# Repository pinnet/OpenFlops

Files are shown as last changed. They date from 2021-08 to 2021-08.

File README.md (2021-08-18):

# OpenFlops
OpenFlops is an Open Hardware Floppy Disk Drive emulator/simulator.

Board

### Summary
From [Wikipedia](https://en.wikipedia.org/wiki/Floppy_disk_hardware_emulator):
> Older models of computers, electronic keyboards and industrial automation often used floppy disk drives for data transfer. Older equipment may be difficult to replace or upgrade because of cost, requirement for continuous availability or unavailable upgrades. Proper operation may require operating system, software and data to be read and written from and to floppies, forcing users to maintain floppy drives on supporting systems.

> Floppy disks and floppy drives are gradually going out of production, and replacement of malfunctioning drives, and the systems hosting them, is becoming increasingly difficult. Floppy disks themselves are fragile, or may need to be replaced often. An alternative is to use a floppy disk hardware emulator, a device which appears to be a standard floppy drive to the old equipment by interfacing directly to the floppy disk controller, while storing data in another medium such as a USB thumb drive, Secure Digital card, or a shared drive on a computer network. Emulators can also be used as a higher-performance replacement for mechanical floppy disk drives. 

OpenFlops is an Open Hardware implementation of such an emulator, inspired from the ubiquitous Gotek hardware. It is designed to run the [FlashFloppy](https://github.com/keirf/FlashFloppy) firmware, which gives it several improvements over the original Gotek:
- Can be installed on [many different platforms](https://github.com/keirf/FlashFloppy/wiki/Host-Platforms)
- Directly supports a [wide range of image formats](https://github.com/keirf/FlashFloppy/wiki/Image-Formats)
- [Flexible track layout](https://github.com/keirf/FlashFloppy/wiki/Track-Layouts) for Raw Sector Images
- [Extremely configurable](https://github.com/keirf/FlashFloppy/wiki/FF.CFG-Configuration-File)
- Supports [AutoSwap](https://github.com/keirf/FF_AutoSwap) for games with a large number of disks
- Easily accessible pin headers for connection of a [i2c display](https://github.com/keirf/FlashFloppy/wiki/Hardware-Mods#lcd-display) (either OLED or LCD), [rotary encoder](https://github.com/keirf/FlashFloppy/wiki/Hardware-Mods#rotary-encoder) (including power)
- Built-in amplified speaker, or easily-accessible pin header for an external one
- USB connector can either be soldered on the board or connected to a pin header
- Connected Motor signal
- Emulates two drives at the same time (Not yet supported by the firmware, but [it will come](https://github.com/keirf/FlashFloppy/wiki/Donations))
- Has additional 3.3V, 5V and GND power pins
- And hey, it's Open Hardware!

All of this comes in the same form factor (and mounting holes) as the board installed in the original Gotek, hence it can be easily installed in any shell or enclosure designed for it.

### Assembly and Installation
Solder all components to the board. I suggest starting with the main microcontroller (U3), as it uses an LQFP package which is tricky to solder: the recommended technique is drag soldering, there are many videos about that on YouTube, so please look there for advice. I recommend soldering the bare minimum components needed for programming and then trying to flash it right away. This way you will be able to fix your soldering without too many components getting in the way, if needed. You will need a USB/TTL Serial converter for this: one with 3.3V I/O level is recommended, but a 5V one can be used, too (most pins on STM32 microcontrollers are 5V-tolerant, so don't worry, it's not a bad hack!). You shouldn't pay more than 1-2€ for it in any case, anyway. So, when you are ready:

- Solder U3, Y1, C3 and C5, then the programming header (the top one with power, BOOT0, TX, RX, etc.)
- Check for shorts on the 3.3V power lines, you can easily do this on the pads for C6-C10
- If your USB/Serial adapter has a 3.3V output, connect it to 3.3V on the power header, then connect ground, RX and TX
- If no 3.3V output is available, solder U4 and power the board through the 5V pin on the power header

Now you should be able to [program the STM32 microcontroller](https://github.com/keirf/FlashFloppy/wiki/Firmware-Programming). If you have difficultes you can try adding R10 (and C4) and maybe a few of C6-C10, but most likely the problem will be with the solder joints on U3, as soldering this kind of package manually is never easy, so please get a lens (or even better, a microscope) and double-check your job.

The serial adapter is only necessary for the first flashing. Subsequent updates [can be done easily via USB](https://github.com/keirf/FlashFloppy/wiki/Firmware-Update).

Note that most components are necessary, but there are a few you can skip if you are feeling lazy:
- If you are not interested in the head movement sound, you can skip the following components: SPK1, D2, R5, R6, Q7.
- If your LCD/OLED display already has pull-up resistors for the SDA/SCK lines (most do), you can skip R3 and R4.

### Configuration
Please refer to the FlashFloppy wiki for the [initial setup](https://github.com/keirf/FlashFloppy/wiki/Initial-Setup) and an overview of the [available configuration options](https://github.com/keirf/FlashFloppy/wiki/FF.CFG-Configuration-File).

Some options that you will want to override the default values of, in order to take advantage of all the features OpenFlops provides, are the following:
- `motor-delay`
- `rotary`
- `display-type`

### Releases
If you want to get this board produced, you are recommended to get [the latest release](https://github.com/SukkoPera/OpenFlops/releases) rather than the current git version, as the latter might be under development and is not guaranteed to be working.

Every release is accompanied by its Bill Of Materials (BOM) file and any relevant notes about it, which you are recommended to read carefully.

### License
The OpenFlops documentation, including the design itself, is copyright &copy; SukkoPera 2019-2020.

OpenFlops is Open Hardware licensed under the [CERN OHL v. 1.2](http://ohwr.org/cernohl).

You may redistribute and modify this documentation under the terms of the CERN OHL v.1.2. This documentation is distributed *as is* and WITHOUT ANY EXPRESS OR IMPLIED WARRANTIES whatsoever with respect to its functionality, operability or use, including, without limitation, any implied warranties OF MERCHANTABILITY, SATISFACTORY QUALITY, FITNESS FOR A PARTICULAR PURPOSE or infringement. We expressly disclaim any liability whatsoever for any direct, indirect, consequential, incidental or special damages, including, without limitation, lost revenues, lost profits, losses resulting from business interruption or loss of data, regardless of the form of action or legal theory under which the liability may be asserted, even if advised of the possibility or likelihood of such damages.

A copy of the full license is included in file [LICENSE.pdf](LICENSE.pdf), please refer to it for applicable conditions. In order to properly deal with its terms, please see file [LICENSE_HOWTO.pdf](LICENSE_HOWTO.pdf).

The contact points for information about manufactured Products (see section 4.2) are listed in file [PRODUCT.md](PRODUCT.md).

Any modifications made by Licensees (see section 3.4.b) shall be recorded in file [CHANGES.md](CHANGES.md).

The Documentation Location of the original project is https://github.com/SukkoPera/OpenFlops/.

### Support the Project
Since the project is open you are free to get the PCBs made by your preferred manufacturer, however in case you want to support the development, you can order them from PCBWay through this link:

PCB from PCBWay (https://www.pcbway.com/project/shareproject/OpenFlops_V1.html)

You get my gratitude and cheap, professionally-made and good quality PCBs, I get some credit that will help with this and [other projects](https://www.pcbway.com/project/member/shareproject/?bmbid=41100). You won't even have to worry about the various PCB options, it's all pre-configured for you!

Also, if you still have to register to that site, [you can use this link](https://www.pcbway.com/setinvite.aspx?inviteid=41100) to get some bonus initial credit (and yield me some more).

Again, if you want to use another manufacturer, feel free to, don't feel obligated :). But then you can buy me a coffee if you want:

<a href='https://ko-fi.com/L3L0U18L' target='_blank'>Buy Me a Coffee at ko-fi.com</a>

### Get Help
If you need help or have questions, you can join [the official Telegram group](https://t.me/joinchat/HUHdWBC9J9JnYIrvTYfZmg).

### Thanks
- H.M for publishing the [original Gotek schematics](doc/gotek_usb-fde_block-diagram.jpg)
- [keirf](https://github.com/keirf) for FlashFloppy
- Brian Allan for suggesting some improvements for the Speaker circuit
- Ray Bellis for suggesting adding pin headers for the USB port and speaker
- Mario Babeu for suggesting to line up the orientation of LD1 and LD2
- Patrick Kerkhof for sending me a lot of original Gotek housing for dimensional testing

# OpenFlopsXT
A remix smaller pcb with support of flashfloppy extensions and a 24pin flat flex connector for a breakout display board that supports SD cards and should fit an Amiga A500 in a mezzanine configuration. This is a work in progress and has not been proven
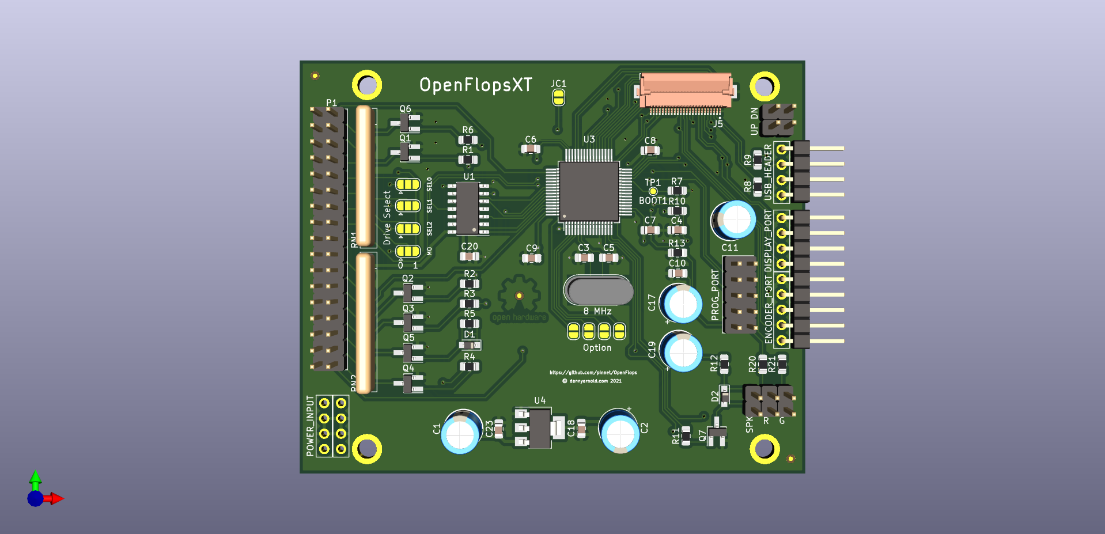
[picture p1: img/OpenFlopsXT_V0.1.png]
PCB Front


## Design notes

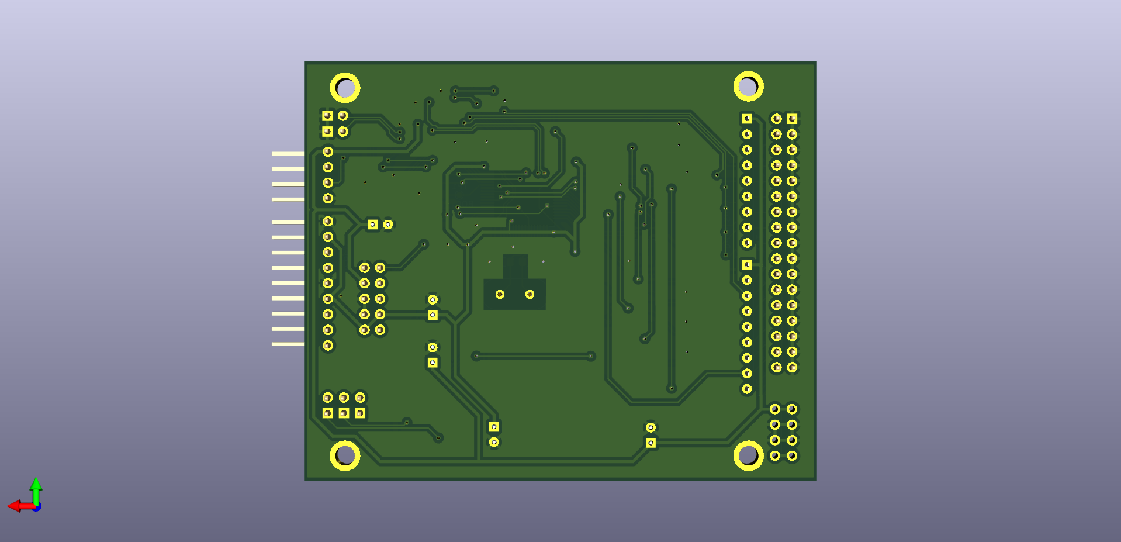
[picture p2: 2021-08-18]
img/OpenFlopsXT_V0.1.bottom.png

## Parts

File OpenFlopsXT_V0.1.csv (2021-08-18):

Source: | D:\dev\OpenFlops\OpenFlopsXT_V0.1.kicad_sch
Date: | 18/08/2021 09:18:35
Tool: | Eeschema (5.99.0-11626-g43523df843)
Generator: | C:\Program Files\KiCad\5.99\bin\scripting\plugins/bom_csv_grouped_by_value_with_fp.py
Component Count: | 77
Ref | Qnty | Value | Cmp name | Footprint | Description | Vendor
C1, | 1 | 100u | CP1 | Jumper:SolderJumper-2_P1.3mm_Open_RoundedPad1.0x1.5mm | Polarized capacitor, US symbol
C2, C11, | 2 | 100u | CP1 | Capacitor_THT:CP_Radial_D6.3mm_P2.50mm | Polarized capacitor, US symbol
C3, C5, | 2 | 22p | C | Capacitor_SMD:C_0805_2012Metric_Pad1.15x1.40mm_HandSolder | Unpolarized capacitor
C4, C6, C7, C8, C9, C10, C18, C20, C23, | 9 | 100n | C | Capacitor_SMD:C_0805_2012Metric_Pad1.15x1.40mm_HandSolder | Unpolarized capacitor
C17, C19, | 2 | 10u | CP1 | Capacitor_THT:CP_Radial_D6.3mm_P2.50mm | Polarized capacitor, US symbol
D1, D2, | 2 | 1N4148 | D | Diode_SMD:D_SOD-323_HandSoldering | Diode
FID1, FID2, FID3, | 3 | Fiducial | Fiducial | Fiducial:Fiducial_0.75mm_Mask1.5mm | Fiducial Marker
H1, H2, H3, H4, | 4 | MountingHole_Pad | MountingHole_Pad | OpenFlops:MountingHole_M3_Pad | Mounting Hole with connection
J1, | 1 | UP | Conn_01x02 | OpenFlops:PinHeader_1x02_P2.54mm_Mute | Generic connector, single row, 01x02, script generated (kicad-library-utils/schlib/autogen/connector/)
J2, | 1 | DN | Conn_01x02 | OpenFlops:PinHeader_1x02_P2.54mm_Mute | Generic connector, single row, 01x02, script generated (kicad-library-utils/schlib/autogen/connector/)
J3, | 1 | R | Conn_01x02 | OpenFlops:PinHeader_1x02_P2.54mm_Mute | Generic connector, single row, 01x02, script generated (kicad-library-utils/schlib/autogen/connector/)
J4, | 1 | G | Conn_01x02 | OpenFlops:PinHeader_1x02_P2.54mm_Mute | Generic connector, single row, 01x02, script generated (kicad-library-utils/schlib/autogen/connector/)
J5, | 1 | Conn_01x22_Female | Conn_01x22_Female | CM4IO:Hirose_FH12-22S-0.5SH_1x22-1MP_P0.50mm_Horizontal | Generic connector, single row, 01x22, script generated (kicad-library-utils/schlib/autogen/connector/)
J6, | 1 | OSHW_LOGO | Conn_01x01 | Symbol:OSHW-Logo2_9.8x8mm_Copper | Generic connector, single row, 01x01, script generated (kicad-library-utils/schlib/autogen/connector/)
JC1, | 1 | Jumper | SolderJumper_2_Open | Jumper:SolderJumper-2_P1.3mm_Open_RoundedPad1.0x1.5mm | Solder Jumper, 2-pole, open
JP1, | 1 | SEL0 | SolderJumper_3_Open | Jumper:SolderJumper-3_P1.3mm_Open_RoundedPad1.0x1.5mm | Solder Jumper, 3-pole, open
JP2, | 1 | SEL1 | SolderJumper_3_Open | Jumper:SolderJumper-3_P1.3mm_Open_RoundedPad1.0x1.5mm | Solder Jumper, 3-pole, open
JP3, | 1 | SEL2 | SolderJumper_3_Open | Jumper:SolderJumper-3_P1.3mm_Open_RoundedPad1.0x1.5mm | Solder Jumper, 3-pole, open
JP4, | 1 | MO | SolderJumper_3_Open | Jumper:SolderJumper-3_P1.3mm_Open_RoundedPad1.0x1.5mm | Solder Jumper, 3-pole, open
JP5, JP6, JP7, JP8, | 4 | SolderJumper_2_Open | SolderJumper_2_Open | Jumper:SolderJumper-2_P1.3mm_Open_RoundedPad1.0x1.5mm | Solder Jumper, 2-pole, open
P1, | 1 | FLOPPY_CONN | Conn_02x17_Odd_Even | Connector_PinHeader_2.54mm:PinHeader_2x17_P2.54mm_Vertical | Generic connector, double row, 02x17, odd/even pin numbering scheme (row 1 odd numbers, row 2 even numbers), script generated (kicad-library-utils/schlib/autogen/connector/)
P2, | 1 | POWER_INPUT | Conn_01x04_Male | OpenFlops:PinHeader_1x04_P2.54mm_Vertical_Power | Generic connector, single row, 01x04, script generated (kicad-library-utils/schlib/autogen/connector/)
P3, | 1 | POWER_PASSTHRU | Conn_01x04_Male | OpenFlops:PinHeader_1x04_P2.54mm_Vertical_Power | Generic connector, single row, 01x04, script generated (kicad-library-utils/schlib/autogen/connector/)
P4, | 1 | PROG_PORT | Conn_02x05_Odd_Even | OpenFlops:PinHeader_2x05_P2.54mm_Vertical | Generic connector, double row, 02x05, odd/even pin numbering scheme (row 1 odd numbers, row 2 even numbers), script generated (kicad-library-utils/schlib/autogen/connector/)
P6, | 1 | ENCODER_PORT | Conn_01x05 | OpenFlops:PinHeader_1x05_P2.54mm_Vertical | Generic connector, single row, 01x05, script generated (kicad-library-utils/schlib/autogen/connector/)
P7, | 1 | DISPLAY_PORT | Conn_01x04 | OpenFlops:PinHeader_1x04_P2.54mm_Vertical | Generic connector, single row, 01x04, script generated (kicad-library-utils/schlib/autogen/connector/)
P8, | 1 | USB_HEADER | Conn_01x04 | OpenFlops:PinHeader_1x04_P2.54mm_Vertical | Generic connector, single row, 01x04, script generated (kicad-library-utils/schlib/autogen/connector/)
P9, | 1 | SPK | Conn_01x02 | OpenFlops:PinHeader_1x02_P2.54mm_Mute | Generic connector, single row, 01x02, script generated (kicad-library-utils/schlib/autogen/connector/)
Q1, Q2, Q3, Q4, Q5, Q6, | 6 | BSS138 | MOS_N_GSD-w_transistor | Package_TO_SOT_SMD:SOT-23_Handsoldering
Q7, | 1 | MMBT3904 | MMBT3904 | Package_TO_SOT_SMD:SOT-23_Handsoldering | 0.2A Ic, 40V Vce, Small Signal NPN Transistor, SOT-23
R1, R2, R3, R4, R5, R6, R11, | 7 | 1K | R | Resistor_SMD:R_0805_2012Metric_Pad1.15x1.40mm_HandSolder | Resistor
R7, R10, R13, | 3 | 4k7 | R | Resistor_SMD:R_0805_2012Metric_Pad1.15x1.40mm_HandSolder | Resistor
R8, R9, R12, | 3 | 22 | R | Resistor_SMD:R_0805_2012Metric_Pad1.15x1.40mm_HandSolder | Resistor
R20, R21, | 2 | 1k | R | Resistor_SMD:R_0805_2012Metric_Pad1.15x1.40mm_HandSolder | Resistor
RN1, RN2, | 2 | R_Network08 | R_Network08 | Resistor_THT:R_Array_SIP9 | 8 resistor network, star topology, bussed resistors, small symbol
TP1, | 1 | BOOT1 | TestPoint | TestPoint:TestPoint_Pad_D1.0mm | test point
U1, | 1 | 74HCT04 | 74HC04 | Package_SO:SOIC-14_3.9x8.7mm_P1.27mm | Hex Inverter
U3, | 1 | STM32F105RBT6 | STM32F105RBTx | OpenFlops:LQFP-64_Handsoldering | ARM Cortex-M3 MCU, 128KB flash, 64KB RAM, 72MHz, 2-3.6V, 51 GPIO, LQFP-64
U4, | 1 | LM1117-3.3 | LM1117-3.3 | Package_TO_SOT_SMD:SOT-223-3_TabPin2 | 800mA Low-Dropout Linear Regulator, 3.3V fixed output, TO-220/TO-252/TO-263/SOT-223
Y1, | 1 | 8 MHz | Crystal | Crystal:Crystal_HC49-U_Vertical | Two pin crystal

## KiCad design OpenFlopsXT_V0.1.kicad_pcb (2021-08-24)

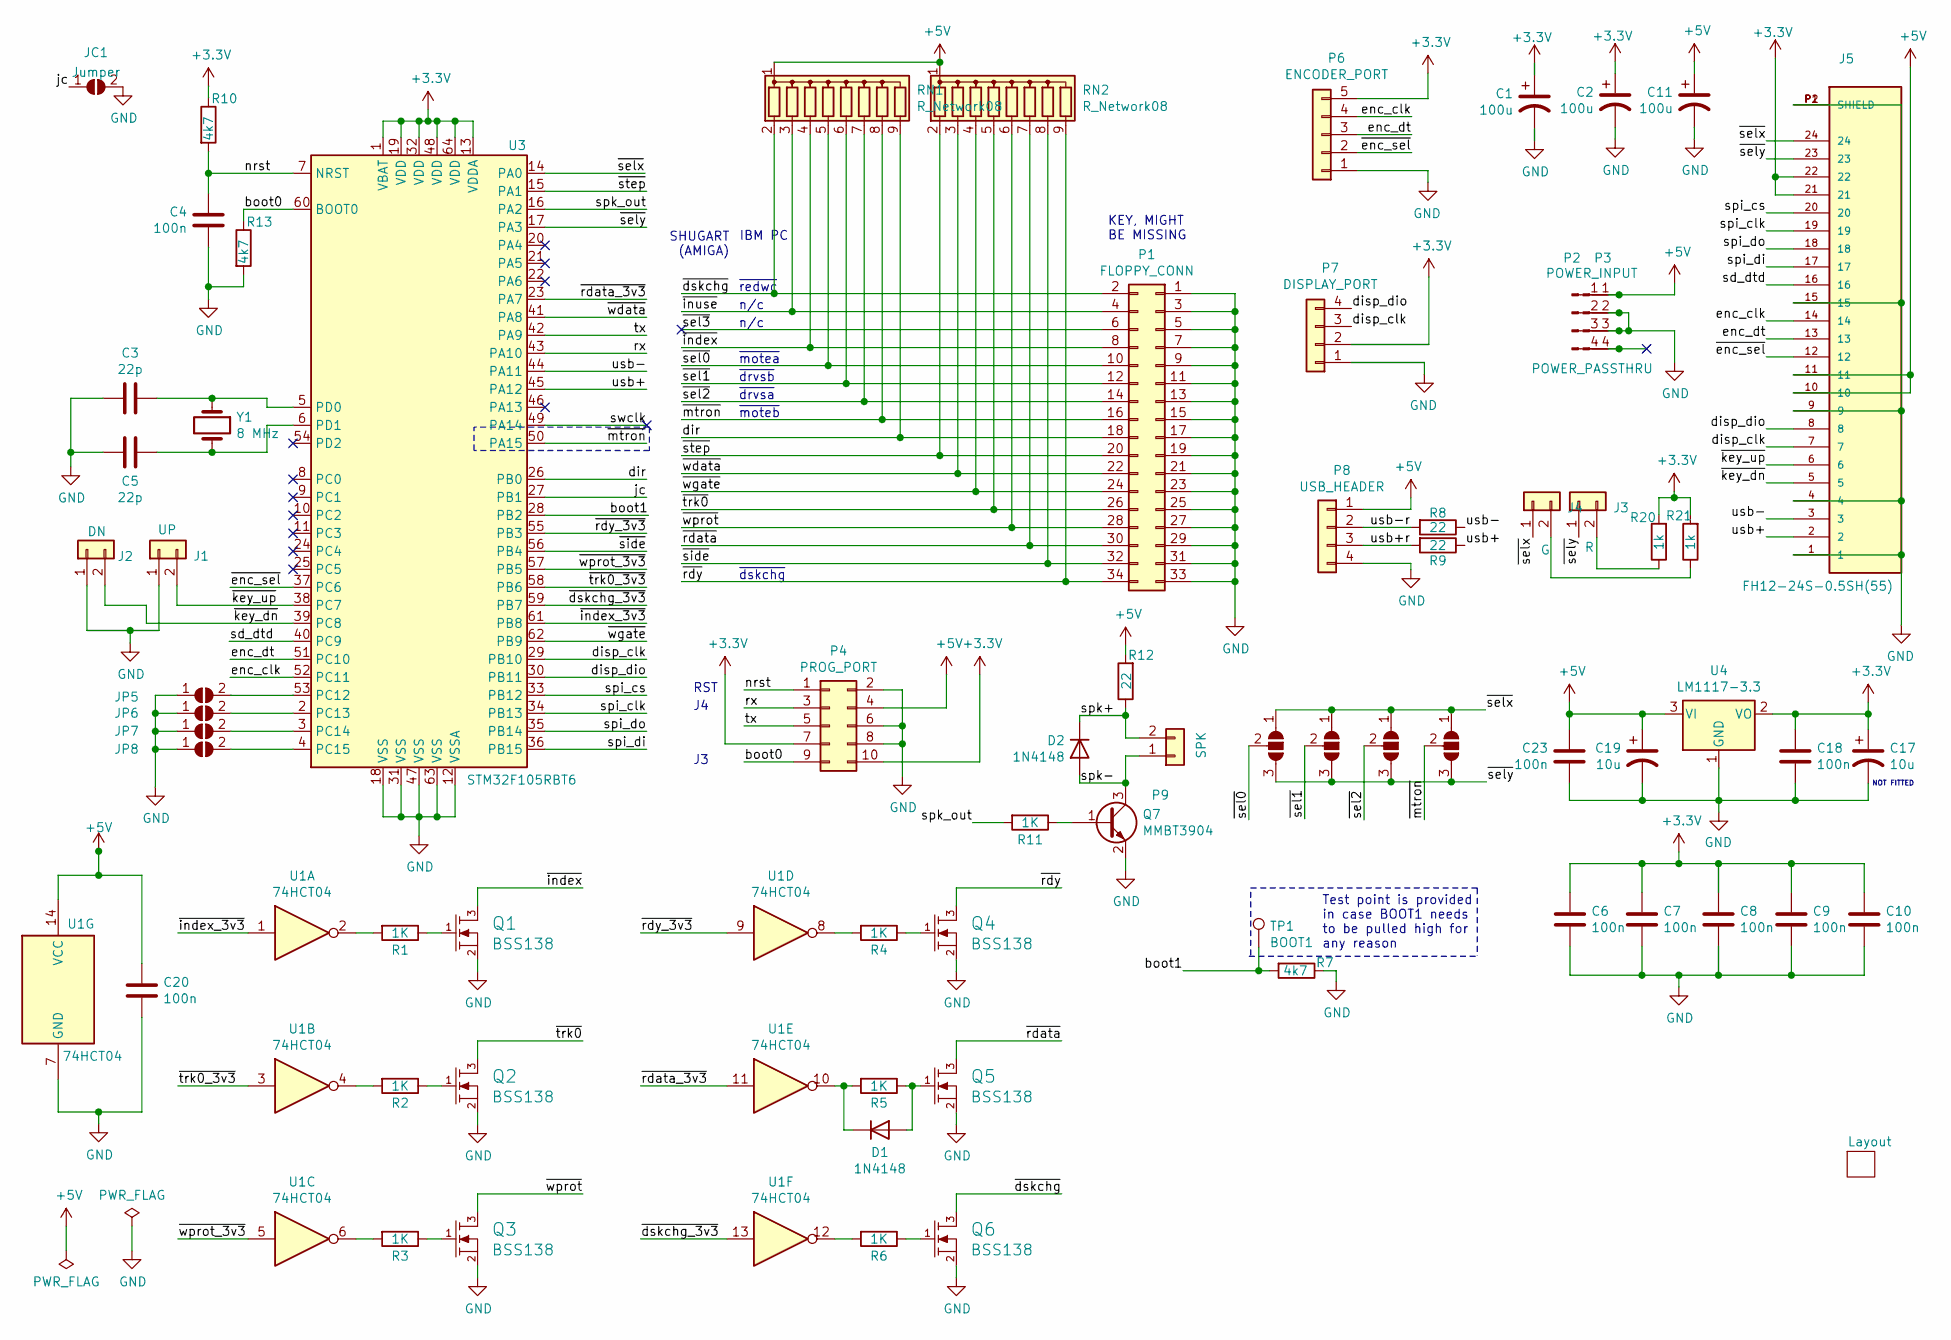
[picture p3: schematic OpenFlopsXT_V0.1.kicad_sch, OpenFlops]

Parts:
C1: 100u; SolderJumper-2_P1.3mm_Open_RoundedPad1.0x1.5mm
C2, C11: 100u; CP_Radial_D6.3mm_P2.50mm
C3, C5: 22p; C_0805_2012Metric_Pad1.15x1.40mm_HandSolder; MFG Part Num MULTILAYER CERAMIC CAPACITORS MLCC - SM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; JLCPCB PN CL21C220JBANNNC
C4, C6, C7, C8, C9, C10, C18, C20, C23: 100n; C_0805_2012Metric_Pad1.15x1.40mm_HandSolder; MFG Part Num MULTILAYER CERAMIC CAPACITORS MLCC - SM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; JLCPCB PN CC0805KRX7R9BB104
C17, C19: 10u; CP_Radial_D6.3mm_P2.50mm
D1, D2: 1N4148; D_SOD-323_HandSoldering; MFG Part Num SWITCHING DIODE 100V 150MA 1.25V @ 150M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; JLCPCB PN 1N4148WS
J1: UP; PinHeader_1x02_P2.54mm_Mute
J2: DN; PinHeader_1x02_P2.54mm_Mute
J3: R; PinHeader_1x02_P2.54mm_Mute
J4: G; PinHeader_1x02_P2.54mm_Mute
J5: FH12-24S-0.5SH(55); HRS_FH12-24S-0.5SH(55)
JC1: Jumper; SolderJumper-2_P1.3mm_Open_RoundedPad1.0x1.5mm
JP1: SEL0; SolderJumper-3_P1.3mm_Open_RoundedPad1.0x1.5mm
JP2: SEL1; SolderJumper-3_P1.3mm_Open_RoundedPad1.0x1.5mm
JP3: SEL2; SolderJumper-3_P1.3mm_Open_RoundedPad1.0x1.5mm
JP4: MO; SolderJumper-3_P1.3mm_Open_RoundedPad1.0x1.5mm
JP5, JP6, JP7, JP8: SolderJumper_2_Open; SolderJumper-2_P1.3mm_Open_RoundedPad1.0x1.5mm
P1: FLOPPY_CONN; PinHeader_2x17_P2.54mm_Vertical
P2: POWER_INPUT; PinHeader_1x04_P2.54mm_Vertical_Power
P3: POWER_PASSTHRU; PinHeader_1x04_P2.54mm_Vertical_Power
P4: PROG_PORT; PinHeader_2x05_P2.54mm_Vertical
P6: ENCODER_PORT; PinHeader_1x05_P2.54mm_Vertical
P7: DISPLAY_PORT; PinHeader_1x04_P2.54mm_Vertical
P8: USB_HEADER; PinHeader_1x04_P2.54mm_Vertical
P9: SPK; PinHeader_1x02_P2.54mm_Mute
Q1, Q2, Q3, Q4, Q5, Q6: BSS138; SOT-23_Handsoldering; MFG Part Num MOSFET N TRENCH 50V 220MA 1.5V @ 1MA 3.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; JLCPCB PN BSS138
Q7: MMBT3904; SOT-23_Handsoldering; MFG Part Num TRANSISTORS (NPN/PNP) NPN 200MA 40V SOT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; JLCPCB PN MMBT3904
R1, R2, R3, R4, R5, R6: 1K; R_0805_2012Metric_Pad1.15x1.40mm_HandSolder; MFG Part Num CHIP RESISTOR - SURFACE MOUNT 1KOHMS ±1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; JLCPCB PN 0805W8F1001T5E
R7, R10, R13: 4k7; R_0805_2012Metric_Pad1.15x1.40mm_HandSolder; MFG Part Num CHIP RESISTOR - SURFACE MOUNT 4.7KOHMS 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; JLCPCB PN 0805W8F4701T5E
R8, R9, R12: 22; R_0805_2012Metric_Pad1.15x1.40mm_HandSolder; MFG Part Num CHIP RESISTOR - SURFACE MOUNT 22OHMS ±1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; JLCPCB PN 0805W8F220JT5E
R11: 1K; R_0805_2012Metric_Pad1.15x1.40mm_HandSolder
R20, R21: 1k; R_0805_2012Metric_Pad1.15x1.40mm_HandSolder
RN1, RN2: R_Network08; R_Array_SIP9
TP1: BOOT1; TestPoint_Pad_D1.0mm
U1: 74HCT04; SOIC-14_3.9x8.7mm_P1.27mm; MFG Part Num GATES AND INVERTERS SOIC-14_150MIL ROHS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; JLCPCB PN 74HCT04D
U3: STM32F105RBT6; LQFP-64_Handsoldering; MFG Part Num ST MICROELECTRONICS LQFP-64_10X10X05P R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; JLCPCB PN STM32F105RBT6
U4: LM1117-3.3; SOT-223-3_TabPin2; MFG Part Num LOW DROPOUT REGULATORS(LDO) POSITIVE FI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; JLCPCB PN AMS1117-3.3
Y1: 8 MHz; Crystal_HC49-U_Vertical

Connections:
+3V3: C1.1, C2.1, C6.1, C7.1, C8.1, C9.1, C10.1, C17.1, C18.1, J5.21, J5.22, P4.7, P4.10, P6.5, P7.2, R10.1, R20.2, R21.2, U3.1 (VBAT), U3.13 (VDDA), U3.19 (VDD), U3.32 (VDD), U3.48 (VDD), U3.64 (VDD), U4.2 (VO)
+5V: C11.1, C19.1, C20.1, C23.1, J5.10, J5.11, P2.1, P3.1, P4.4, P8.1, R12.2, RN1.1 (common), RN2.1 (common), U1.14 (VCC), U4.3 (VI)
/boot0: P4.9, R13.1, U3.60 (BOOT0)
/boot1: R7.2, TP1.1, U3.28 (PB2)
/dir: P1.18, RN1.9 (R8), U3.26 (PB0)
/disp_clk: J5.7, P7.3, U3.29 (PB10)
/disp_dio: J5.8, P7.4, U3.30 (PB11)
/enc_clk: J5.14, P6.4, U3.52 (PC11)
/enc_dt: J5.13, P6.3, U3.51 (PC10)
/jc: JC1.1 (A), U3.27 (PB1)
/nrst: C4.1, P4.1, R10.2, U3.7 (NRST)
/rx: P4.3, U3.43 (PA10)
/sd_dtd: J5.16, U3.40 (PC9)
/spi_clk: J5.19, U3.34 (PB13)
/spi_cs: J5.20, U3.33 (PB12)
/spi_di: J5.17, U3.36 (PB15)
/spi_do: J5.18, U3.35 (PB14)
/spk+: D2.1 (K), P9.2, R12.1
/spk-: D2.2 (A), P9.1, Q7.3 (C)
/spk_out: R11.2, U3.16 (PA2)
/swclk: U3.49 (PA14)
/tx: P4.5, U3.42 (PA9)
/usb+: J5.2, R9.1, U3.45 (PA12)
/usb+r: P8.3, R9.2
/usb-: J5.3, R8.1, U3.44 (PA11)
/usb-r: P8.2, R8.2
/~dskchg_3v3: U1.13, U3.59 (PB7)
/~dskchg: P1.2, Q6.3 (D), RN1.2 (R1)
/~enc_sel: J5.12, P6.2, U3.37 (PC6)
/~index_3v3: U1.1, U3.61 (PB8)
/~index: P1.8, Q1.3 (D), RN1.4 (R3)
/~inuse: P1.4, RN1.3 (R2)
/~key_dn: J2.2, J5.5, U3.39 (PC8)
/~key_up: J1.2, J5.6, U3.38 (PC7)
/~mtron: JP4.2 (C), P1.16, RN1.8 (R7), U3.50 (PA15)
/~rdata_3v3: U1.11, U3.23 (PA7)
/~rdata: P1.30, Q5.3 (D), RN2.7 (R6)
/~rdy_3v3: U1.9, U3.55 (PB3)
/~rdy: P1.34, Q4.3 (D), RN2.9 (R8)
/~sel0: JP1.2 (C), P1.10, RN1.5 (R4)
/~sel1: JP2.2 (C), P1.12, RN1.6 (R5)
/~sel2: JP3.2 (C), P1.14, RN1.7 (R6)
/~sel3: P1.6
/~selx: J4.1, J5.24, JP1.1 (A), JP2.1 (A), JP3.1 (A), JP4.1 (A), U3.14 (PA0)
/~sely: J3.1, J5.23, JP1.3 (B), JP2.3 (B), JP3.3 (B), JP4.3 (B), U3.17 (PA3)
/~side: P1.32, RN2.8 (R7), U3.56 (PB4)
/~step: P1.20, RN2.2 (R1), U3.15 (PA1)
/~trk0_3v3: U1.3, U3.58 (PB6)
/~trk0: P1.26, Q2.3 (D), RN2.5 (R4)
/~wdata: P1.22, RN2.3 (R2), U3.41 (PA8)
/~wgate: P1.24, RN2.4 (R3), U3.62 (PB9)
/~wprot_3v3: U1.5, U3.57 (PB5)
/~wprot: P1.28, Q3.3 (D), RN2.6 (R5)
GND: C1.2, C2.2, C3.2, C4.2, C5.2, C6.2, C7.2, C8.2, C9.2, C10.2, C11.2, C17.2, C18.2, C19.2, C20.2, C23.2, J1.1, J2.1, J5.1, J5.4, J5.9, J5.15, J5.P1 (SHIELD), J5.P2 (SHIELD), JC1.2 (B), JP5.1 (A), JP6.1 (A), JP7.1 (A), JP8.1 (A), P1.1, P1.3, P1.5, P1.7, P1.9, P1.11, P1.13, P1.15, P1.17, P1.19, P1.21, P1.23, P1.25, P1.27, P1.29, P1.31, P1.33, P2.2, P2.3, P3.2, P3.3, P4.2, P4.6, P4.8, P6.1, P7.1, P8.4, Q1.2 (S), Q2.2 (S), Q3.2 (S), Q4.2 (S), Q5.2 (S), Q6.2 (S), Q7.2 (E), R7.1, R13.2, U1.7 (GND), U3.12 (VSSA), U3.18 (VSS), U3.31 (VSS), U3.47 (VSS), U3.63 (VSS), U4.1 (GND); also elsewhere on the board
unnamed: C3.1, U3.5 (PD0), Y1.1
unnamed: C5.1, U3.6 (PD1), Y1.2
unnamed: D1.1 (K), R5.2, U1.10
unnamed: D1.2 (A), Q5.1 (G), R5.1
unnamed: J3.2, R20.1
unnamed: J4.2, R21.1
unnamed: JP5.2 (B), U3.53 (PC12)
unnamed: JP6.2 (B), U3.2 (PC13)
unnamed: JP7.2 (B), U3.3 (PC14)
unnamed: JP8.2 (B), U3.4 (PC15)
unnamed: P2.4, P3.4
unnamed: Q1.1 (G), R1.1
unnamed: Q2.1 (G), R2.1
unnamed: Q3.1 (G), R3.1
unnamed: Q4.1 (G), R4.1
unnamed: Q6.1 (G), R6.1
unnamed: Q7.1 (B), R11.1
unnamed: R1.2, U1.2
unnamed: R2.2, U1.4
unnamed: R3.2, U1.6
unnamed: R4.2, U1.8
unnamed: R6.2, U1.12

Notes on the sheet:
RST
SHUGART (AMIGA)
~{redwc}
n/c
~{motea}
~{drvsb}
~{drvsa}
~{moteb}
~{dskchg}
IBM PC
KEY, MIGHT BE MISSING
Test point is provided in case BOOT1 needs to be pulled high for any reason
NOT FITTED

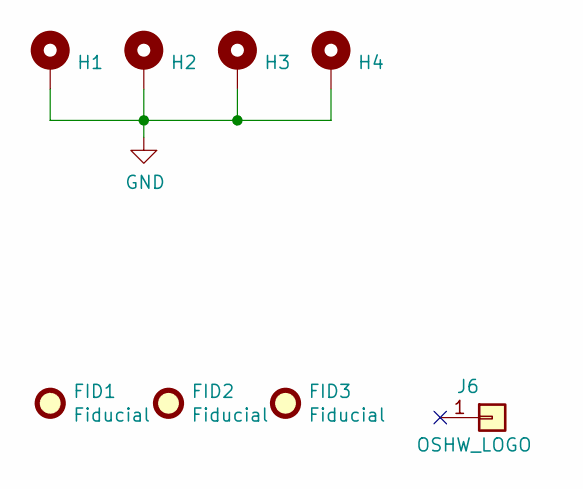
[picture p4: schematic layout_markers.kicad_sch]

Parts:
FID1, FID2, FID3: Fiducial; Fiducial_0.75mm_Mask1.5mm
H1, H2, H3, H4: MountingHole_Pad; MountingHole_M3_Pad
J6: OSHW_LOGO; OSHW-Logo2_9.8x8mm_Copper

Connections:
GND: H1.1, H2.1, H3.1, H4.1; also elsewhere on the board

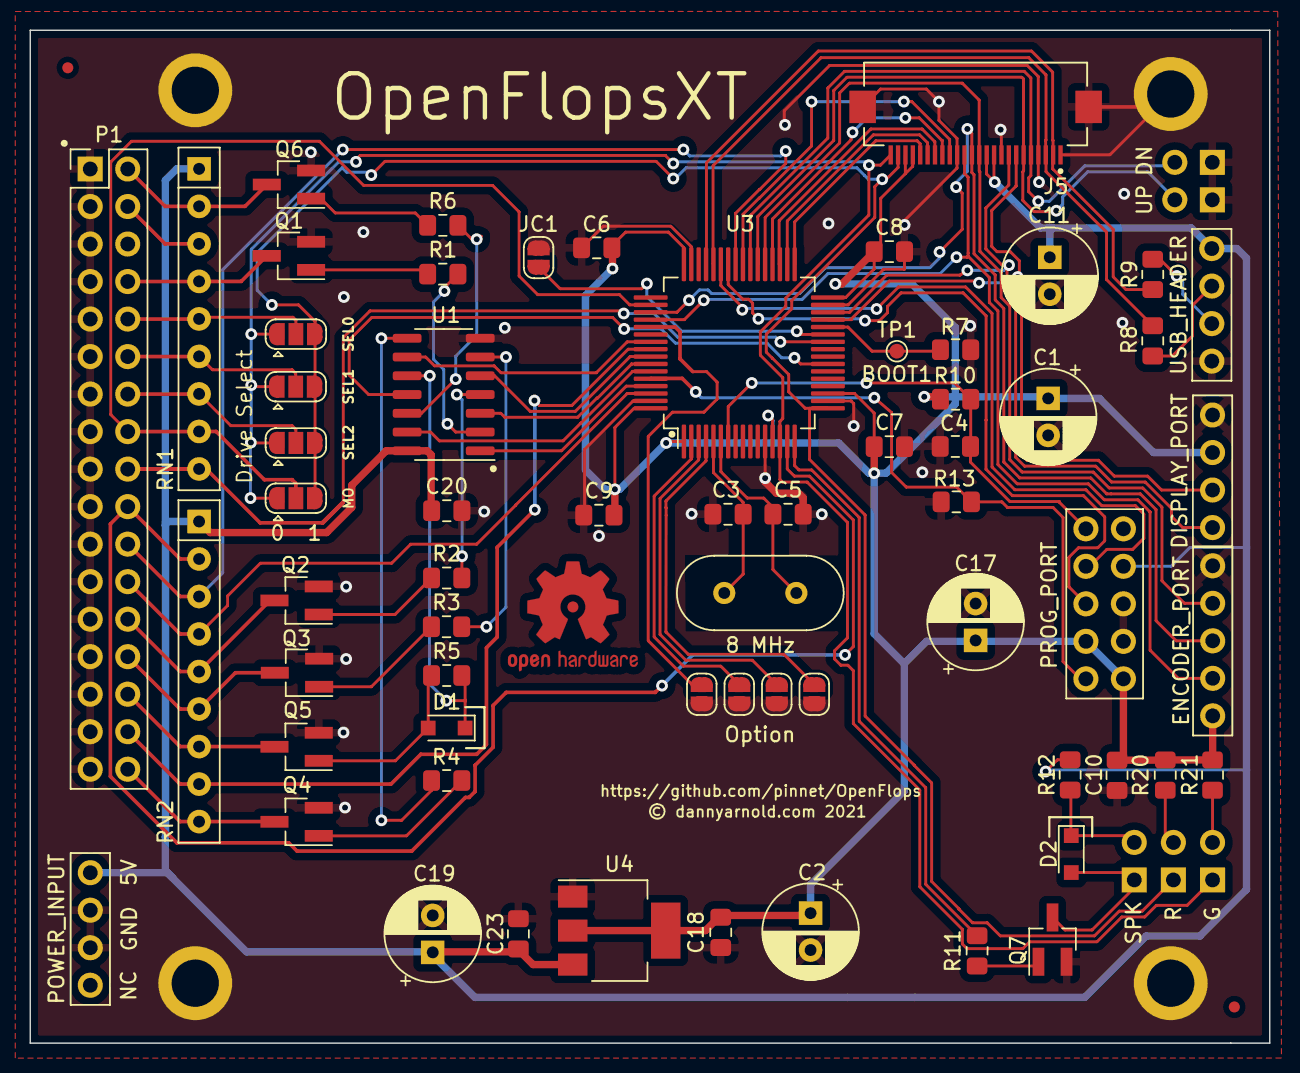
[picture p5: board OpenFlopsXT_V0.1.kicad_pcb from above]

Board: 2 copper layers, 83.9 x 68.6 mm, 76 parts (0 on the bottom side), 73 nets.

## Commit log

2021-08-09 Added Cost Reduced version
    [OpenFlopsShort-B_Cu.gbr, OpenFlopsShort-B_Mask.gbr, OpenFlopsShort-B_Paste.gbr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]
2021-08-18 OpenFlopsXT initial commit
    [OpenFlopsShort-B_Cu.gbr, OpenFlopsShort-B_Mask.gbr, OpenFlopsShort-B_Paste.gbr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]
2021-08-18 Corrected Github URL
    [OpenFlopsXT_V0.1.kicad_pcb]
2021-08-18 Fixed DRC on OpenFlopsXT
    [OpenFlopsXT_V0.1.csv, OpenFlopsXT_V0.1.kicad_pcb]
2021-08-18 Upgraded Flat Flex Connector OpenFlopsXT
    [OpenFlopsXT_V0.1-B_Cu.gbr, OpenFlopsXT_V0.1-B_Mask.gbr, OpenFlopsXT_V0.1-B_Paste.gbr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]
2021-08-18 Added 3d images of OpenFlopsXT
    [OpenFlopsXT_V0.1.kicad_pcb]
2021-08-24 Tidy up OpenFlopsXT for manufature
    [OpenFlopsXT_V0.1.kicad_pcb, OpenFlopsXT_V0.1.kicad_sch]
2021-08-24 Correct missing pin 1 locators and Tidy up OpenfFLopsXT
    [OpenFlopsXT_V0.1.kicad_pcb, OpenFlopsXT_V0.1.kicad_sch]
2021-08-24 Retreve from backup due to git error
    [OpenFlopsXT_V0.1.kicad_pcb, OpenFlopsXT_V0.1.kicad_sch]
2021-08-24 Cleanup and fix silkscreen isue. OpenFlopsXT
    [OpenFlopsXT_V0.1.kicad_pcb]

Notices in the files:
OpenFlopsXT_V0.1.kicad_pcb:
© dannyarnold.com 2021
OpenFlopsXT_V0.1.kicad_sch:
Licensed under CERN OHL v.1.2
